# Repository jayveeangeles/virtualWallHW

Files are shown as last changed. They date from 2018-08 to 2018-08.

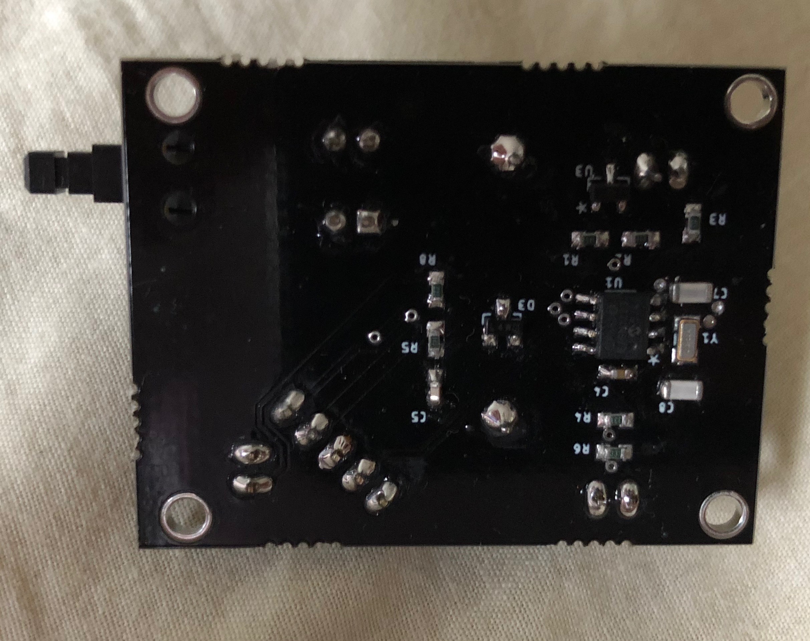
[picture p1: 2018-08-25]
JPG/virtual_wall_lp_back.jpg

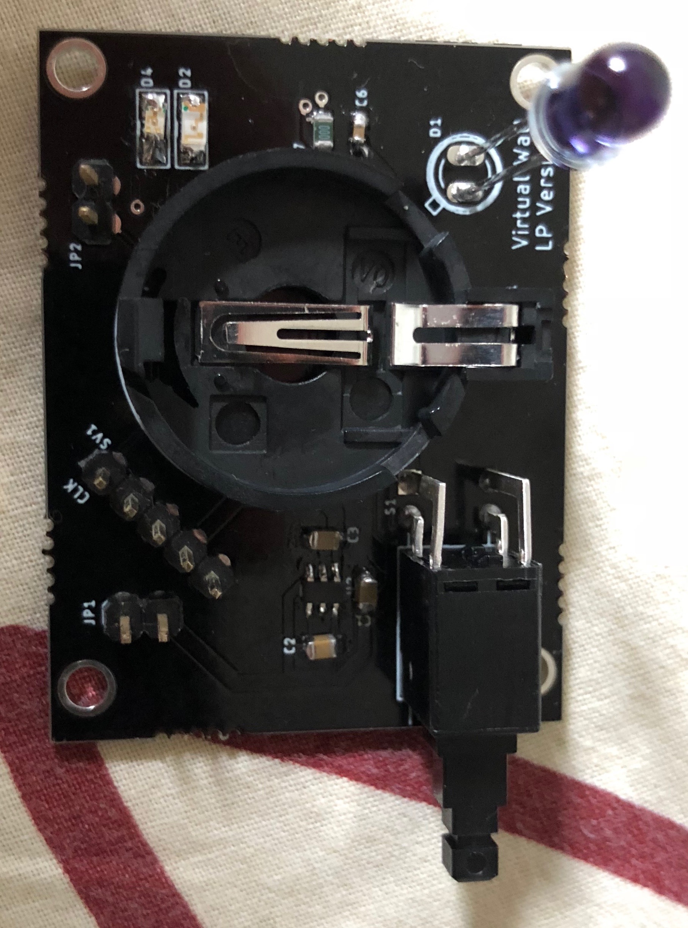
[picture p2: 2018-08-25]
JPG/virtual_wall_lp_front.jpg

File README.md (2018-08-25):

# virtualWallHW

## Project Brief:
Repository to hold EAGLE files for Roomba Virtual Wall using PIC12F683

## Notes:
1) R7 was replaced by a 0 ohm resistor. 
2) C6 was also removed from the circuit. 
3) [SeeedStudio script](http://support.seeedstudio.com/knowledgebase/articles/1176949-how-to-generate-gerber-file-from-eagle) was used to generate manufacturing files.
4) Only the panelized brd file is included in this package. The schematic of the other board will be posted once that has been verified.

## Firmware:
[Firmware link](https://github.com/jayveeangeles/virtualWallFW)

## References:
1) [High-Speed Layout Guidelines](http://www.ti.com/lit/an/scaa082a/scaa082a.pdf)
2) [Oscillator](http://ww1.microchip.com/downloads/en/DeviceDoc/31002a.pdf)
3) [EXTERNAL 32.768 KHZ CRYSTAL OSCILLATOR](https://www.silabs.com/documents/public/application-notes/AN299.pdf)
4) [Choosing the Right Crystal and Caps for your Design](https://blog.adafruit.com/2012/01/24/choosing-the-right-crystal-and-caps-for-your-design/)
5) [Summary of Eagle PCB Layout Guidelines](https://iotexpert.com/2016/11/16/eagle-pcb-layout-guidelines-osh-park/)
6) [Using EAGLE: Board Layout](https://learn.sparkfun.com/tutorials/using-eagle-board-layout)
7) [Adding copper pour in EAGLE](https://www.lucidar.me/en/eagle/adding-copper-pour-in-eagle/)
8) [EAGLE: Panelizing made easy](https://smdprutser.nl/blog/eagle-panelizing-made-easy/)

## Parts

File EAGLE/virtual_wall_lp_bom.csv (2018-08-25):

Qty | Value | Device | Package | Parts | Description | AVAILABILITY | DESCRIPTION | MF | MP | MPN | OC_FARNELL | OC_NEWARK | PACKAGE | PRICE | SPICEPREFIX | SUPPLIER
2 |  | LED1206 | CHIPLED_1206 | D2, D4 | LED
2 |  | PINHD-1X2 | 1X02 | JP1, JP2 | PIN HEADER
1 |  | PINHD-1X5 | 1X05 | SV1 | PIN HEADER
1 | 0 | R-US_R0603 | R0603 | R7 | RESISTOR, American symbol |  |  |  |  |  |  |  |  |  | R
3 | 0.1u | C-EUC0603 | C0603 | C4, C5, C6 | CAPACITOR, European symbol
1 | 1066 | 1066 | 1066 | G1 | Keystone 1066 Li Coin Cell Holder | Good | Coin Cell Holder | 20 mm | 0.896 in. | Glass Filled Nylon | Tin Plate | 1 | Greenlee Communications | 1066
2 | 10K | R-US_R0603 | R0603 | R2, R5 | RESISTOR, American symbol |  |  |  |  |  |  |  |  |  | R
2 | 12p | C-EUC0603 | C0603 | C7, C8 | CAPACITOR, European symbol
1 | 1K | R-US_R0603 | R0603 | R8 | RESISTOR, American symbol |  |  |  |  |  |  |  |  |  | R
3 | 1u | C-EUC0603 | C0603 | C1, C2, C3 | CAPACITOR, European symbol
2 | 330 | R-US_R0603 | R0603 | R4, R6 | RESISTOR, American symbol |  |  |  |  |  |  |  |  |  | R
1 | 51 | R-US_R0603 | R0603 | R3 | RESISTOR, American symbol |  |  |  |  |  |  |  |  |  | R
1 | 510 | R-US_R0603 | R0603 | R1 | RESISTOR, American symbol |  |  |  |  |  |  |  |  |  | R
1 | BAT54 | BAT54 | SOT23 | D3 | Schottky barrier diodePlanar Schottky barrier diode encapsulated in small plastic SMD packages. Single diodes and double
1 | BSS138-7-F | BSS138-7-F | SOT95P240X110-3N | U3 | ENHANCEMENT MODE MOSFET |  |  |  |  | BSS138-7-F | 1843693 | 12T1442 | SOT-23-3 |  |  | DIODES INC.
1 | CAT3200TDI-GT3 | CAT3200TDI-GT3 | SOT95P280X100-6N | U2 | DC-DC Converter | Good | Regulated Charge Pump, Low Noise, DC-DC Converter | ON Semiconductor | CAT3200TDI-GT3 |  |  |  | TSOT-23-6 ON Semiconductor | 0.79 USD
1 | CRYSTAL.ABS07 | CRYSTAL.ABS07 | ABS07 | Y1
1 | PB400EEQX | PB400EEQX | SW_PB400EEQX | S1 | Right Angle Pushbutton Switch | Warning | Right Angle Pushbutton Switch | E-Switch | PB400EEQX |  |  |  | None | 0.96 USD
1 | PIC12F683-I/SN | PIC12F683-I/SN | SOIC127P600X175-8N | U1 | IC, 8BIT MCU, PIC12, 20MHZ |  |  |  |  | PIC12F683-I/SN | 9759042 | 61K3434 | SOIC-8 |  |  | MICROCHIP
1 | SFH482 | SFH482 | SFH482 | D1 | IR LED

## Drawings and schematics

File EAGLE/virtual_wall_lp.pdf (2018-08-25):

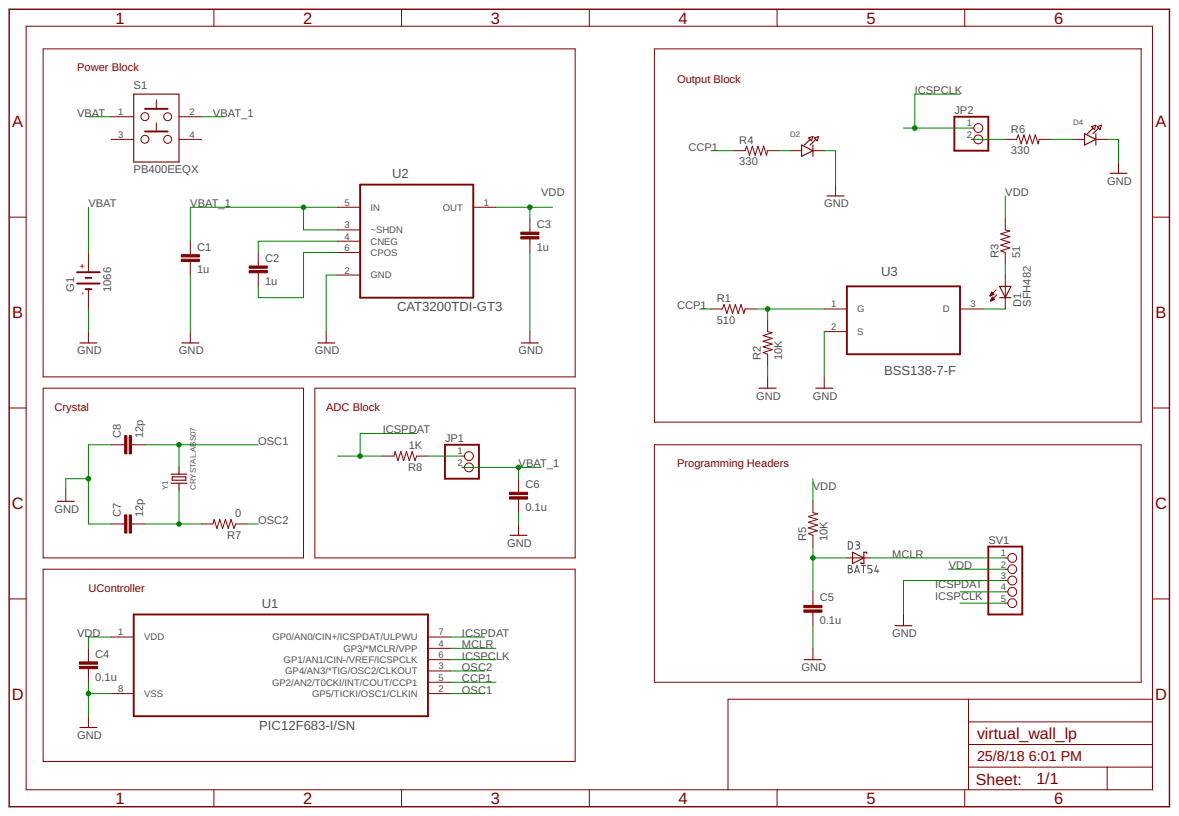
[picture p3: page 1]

1066 GND GND GND GND

Programming Headers ADC Block

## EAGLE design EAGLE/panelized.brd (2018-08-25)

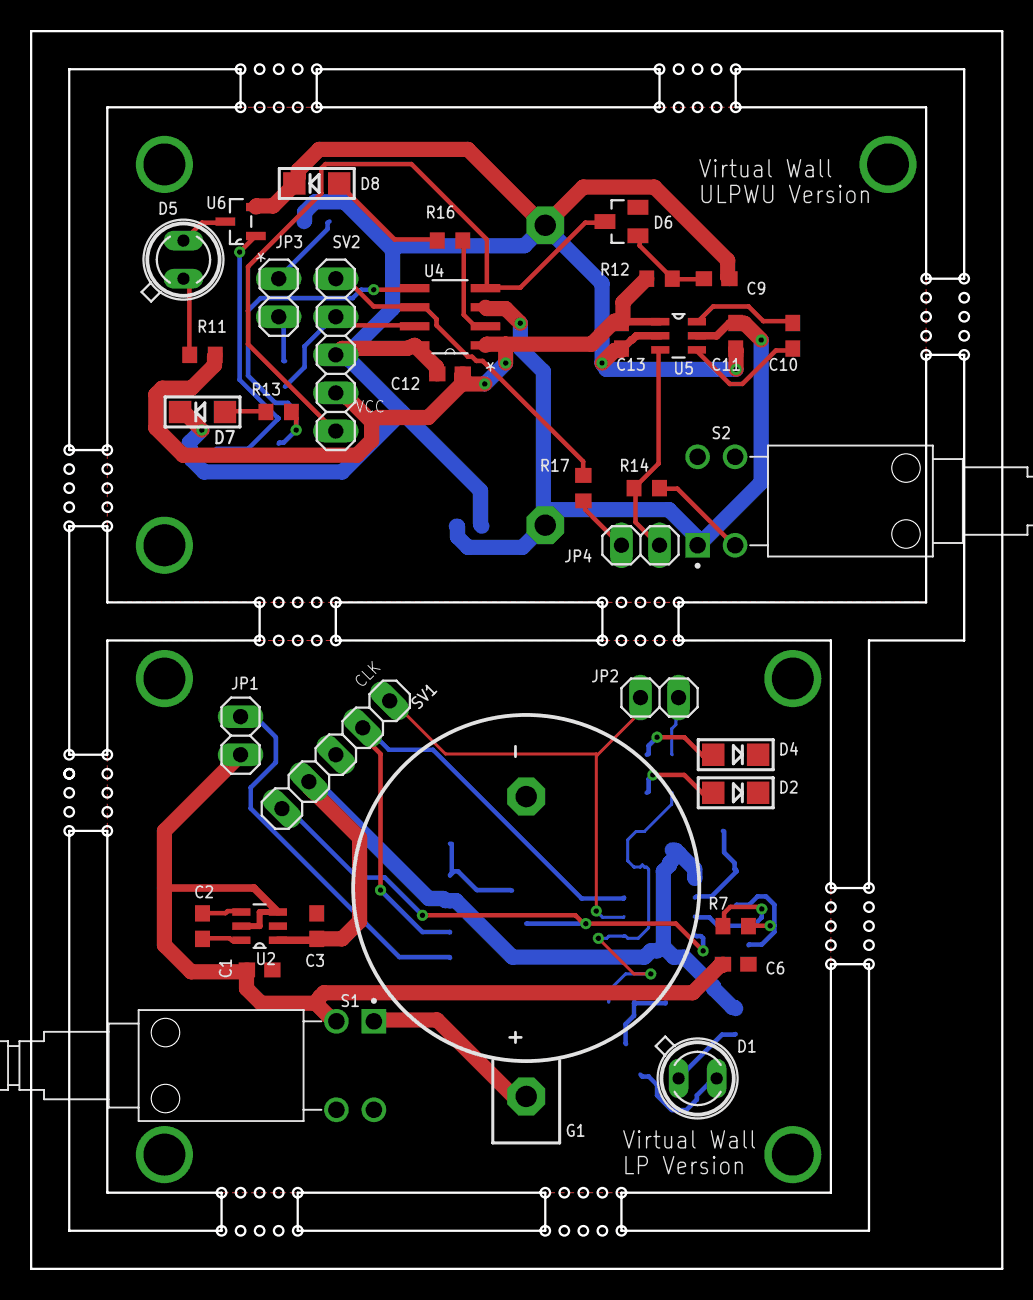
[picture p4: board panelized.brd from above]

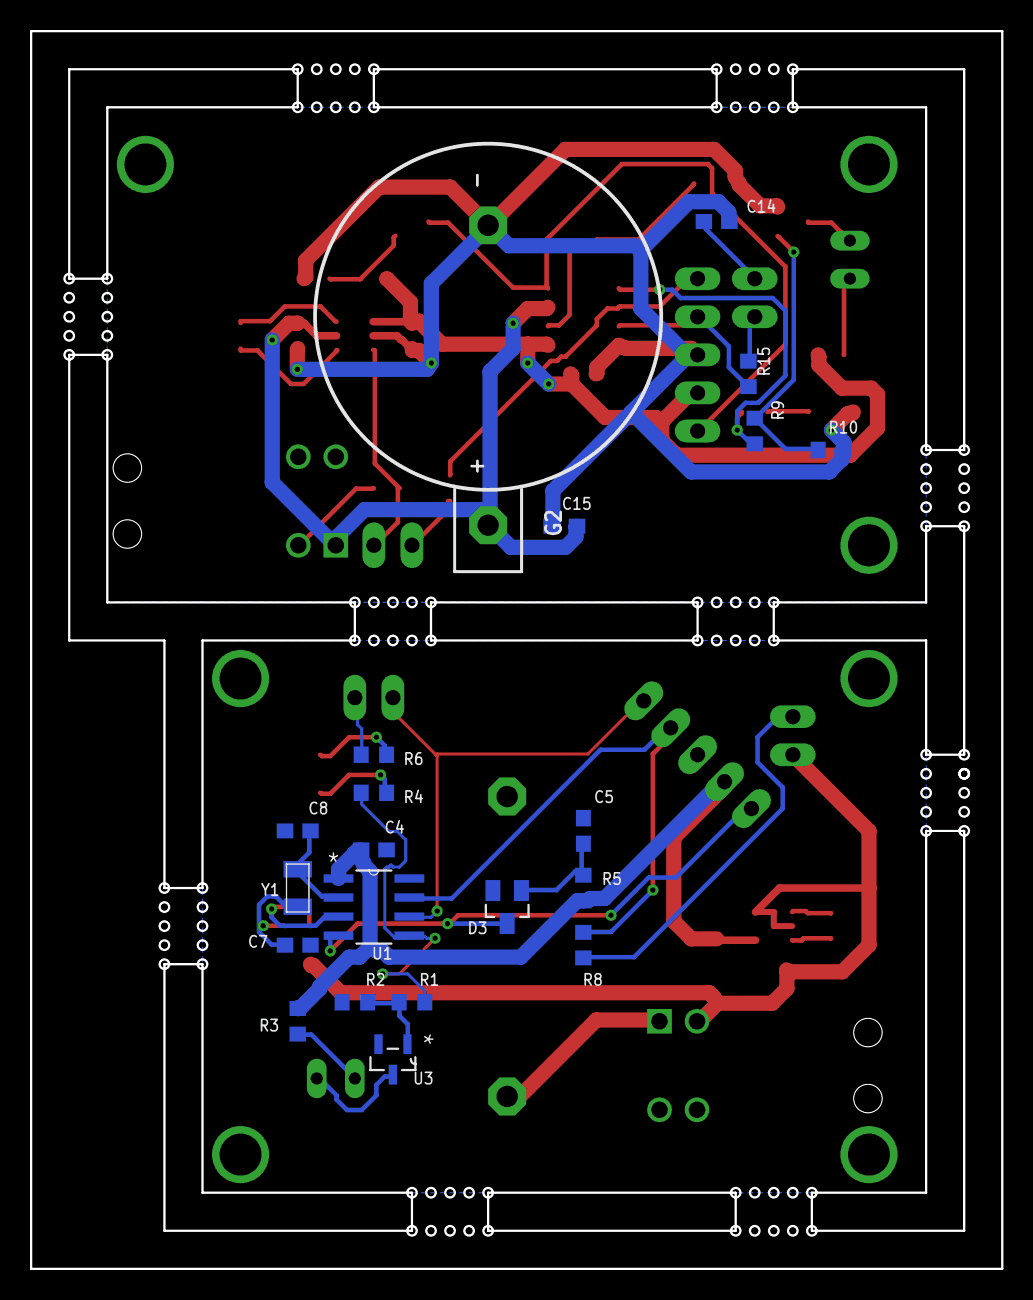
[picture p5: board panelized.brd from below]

Board: 2 copper layers, 64.8 x 82.6 mm, 57 parts (21 on the bottom side), 42 nets.

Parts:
C1, C2, C3, C10, C11, C13: 1u; C0603
C4, C5, C6, C9, C12, C15: 0.1u; C0603
C7, C8: 12p; C0603
C14: 50n; C0603
D1, D5: SFH482
D2, D4, D7, D8: CHIPLED_1206
D3, D6: BAT54; SOT23
G1, G2: 1066
JP1, JP2, JP3, JP4: 1X02
R1, R9: 510; R0603
R2, R5, R10, R12, R17: 10K; R0603
R3, R11: 51; R0603
R4, R6, R13, R16: 330; R0603
R7: 100; R0603
R8, R14: 1K; R0603
R15: 220; R0603
S1, S2: PB400EEQX; SW_PB400EEQX
SV1, SV2: 1X05
U1, U4: PIC12F683-I/SN; SOIC127P600X175-8N
U2, U5: CAT3200TDI-GT3; SOT95P280X100-6N
U3, U6: BSS138-7-F; SOT95P240X110-3N
Y1: CRYSTAL.ABS07; ABS07

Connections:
/SHDN: JP4.2, R14.1, U5.3
CCP1: R1.1, R4.1, U1.5
CCP2: R9.1, R13.1, U4.5
GND: C1.2, C3.2, C4.2, C5.2, C6.2, C7.1, C8.1, D2.C, D4.C, G1.-, R2.1, SV1.3, U1.8, U2.2, U3.2
GND1: C9.2, C11.2, C12.2, C13.2, C14.2, C15.2, D7.C, D8.C, G2.-, R10.1, SV2.3, U4.8, U5.2, U6.2
GP5: R16.1, U4.2
ICSPCLK: JP2.1, SV1.5, U1.6
ICSPCLK1: R17.2, SV2.5, U4.6
ICSPDAT: R8.2, SV1.4, U1.7
ICSPDAT1: R15.2, SV2.4, U4.7
MCLR: D3.3, SV1.1, U1.4
MCLR1: D6.3, SV2.1, U4.4
unnamed: C2.1, U2.4
unnamed: R1.2, R2.2, U3.1
unnamed: C2.2, U2.6
unnamed: D2.A, R4.2
unnamed: D1.A, R3.1
unnamed: D1.K, U3.3
unnamed: C5.1, D3.1, R5.1
unnamed: C7.2, R7.2, Y1.1
unnamed: D4.A, R6.2
unnamed: JP2.2, R6.1
unnamed: JP1.1, R8.1
unnamed: R9.2, R10.2, U6.1
unnamed: D5.A, R11.1
unnamed: D5.K, U6.3
unnamed: C9.1, D6.1, R12.1
unnamed: C10.2, U5.6
unnamed: C10.1, U5.4
unnamed: D7.A, R13.2
unnamed: R14.2, S2.2
unnamed: D8.A, R16.2
unnamed: C14.1, JP3.2
unnamed: JP4.1, R17.1
unnamed: JP3.1, R15.1
OSC1: C8.2, U1.2, Y1.2
OSC2: R7.1, U1.3
VBAT: G1.+, S1.1
VBAT1: C11.1, C15.1, G2.+, S2.1, U4.3, U5.5
VBAT_1: C1.1, C6.1, JP1.2, S1.2, U2.3, U2.5
VDD: C3.1, C4.1, R3.2, R5.2, SV1.2, U1.1, U2.1
VDD1: C12.1, C13.1, R11.2, R12.2, SV2.2, U4.1, U5.1

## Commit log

2018-08-25 committing schematic and brd file(panelized) of the virtual wall LP version
    [panelized.brd, virtual_wall_lp.csv, virtual_wall_lp.sch]
2018-08-25 re-rendered BOM file and renamed filename
    [virtual_wall_lp.csv, virtual_wall_lp_bom.csv]
2018-08-25 added missing net from charge pump to ucontroller vdd
    [virtual_wall_lp.sch]

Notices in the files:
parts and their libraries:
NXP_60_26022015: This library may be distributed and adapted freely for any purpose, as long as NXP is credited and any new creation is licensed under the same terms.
